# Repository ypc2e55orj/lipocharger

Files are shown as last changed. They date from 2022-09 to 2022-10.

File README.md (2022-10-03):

# Li-Po Charger

小容量リポバッテリー充電器





## 仕様

- 電源入力 (5V)
    - USB Type-C
    - 2.54mm ピンヘッダ
- 充電電圧・電流 (1個あたり)
    - 4.2V / 50mA

USB Type-Cとピンヘッダから同時に入力された場合、ピンヘッダからの入力を優先する

充電中赤色LED点灯、充電完了時に消灯

## 部品リスト

|概説|メーカー|型番|個数|
|:-:|:-:|:-:|:-:|
|USB Type-Cコネクタ|Korean Hroparts Elec|TYPE-C-31-M-12|1|
|ZHコネクタ|JST|B2B-ZR-3.4(LF)(SN)|4|
|2.54mmピッチ ピンヘッダ 2P|||1|
|リセッタブルヒューズ|Bourns|MF-NSMF050-2|1|
|ショットキーバリアダイオード|東芝セミコンダクター|CUHS20S60|2|
|Pch MOS-FET|International Rectifier|IRLML6402|1|
|青色LED|OptoSupply|OSBL1608C1A|1|
|黄色LED|OptoSupply|OSYL1608C1A|1|
|赤色LED|OptoSupply|OSHR1608C1A|4|
|積層セラミックコンデンサ|muRata|GRM188R71E105KA12|4|
|薄膜抵抗器 5.1kΩ|Panasonic|ERA-3AED512V|2|
|薄膜抵抗器 430Ω|Panasonic|ERA-3AED431V|1|
|薄膜抵抗器 1kΩ|Panasonic|ERA-3AED102V|1|
|薄膜抵抗器 680Ω|Panasonic|ERA-3AED681V|5|
|薄膜抵抗器 20kΩ|Panasonic|ERA-3AED203V|4|
|Li-Ion充電管理IC|Analog Devices|LTC4054XES5-4.2|4|

## LICENSE

The MIT License

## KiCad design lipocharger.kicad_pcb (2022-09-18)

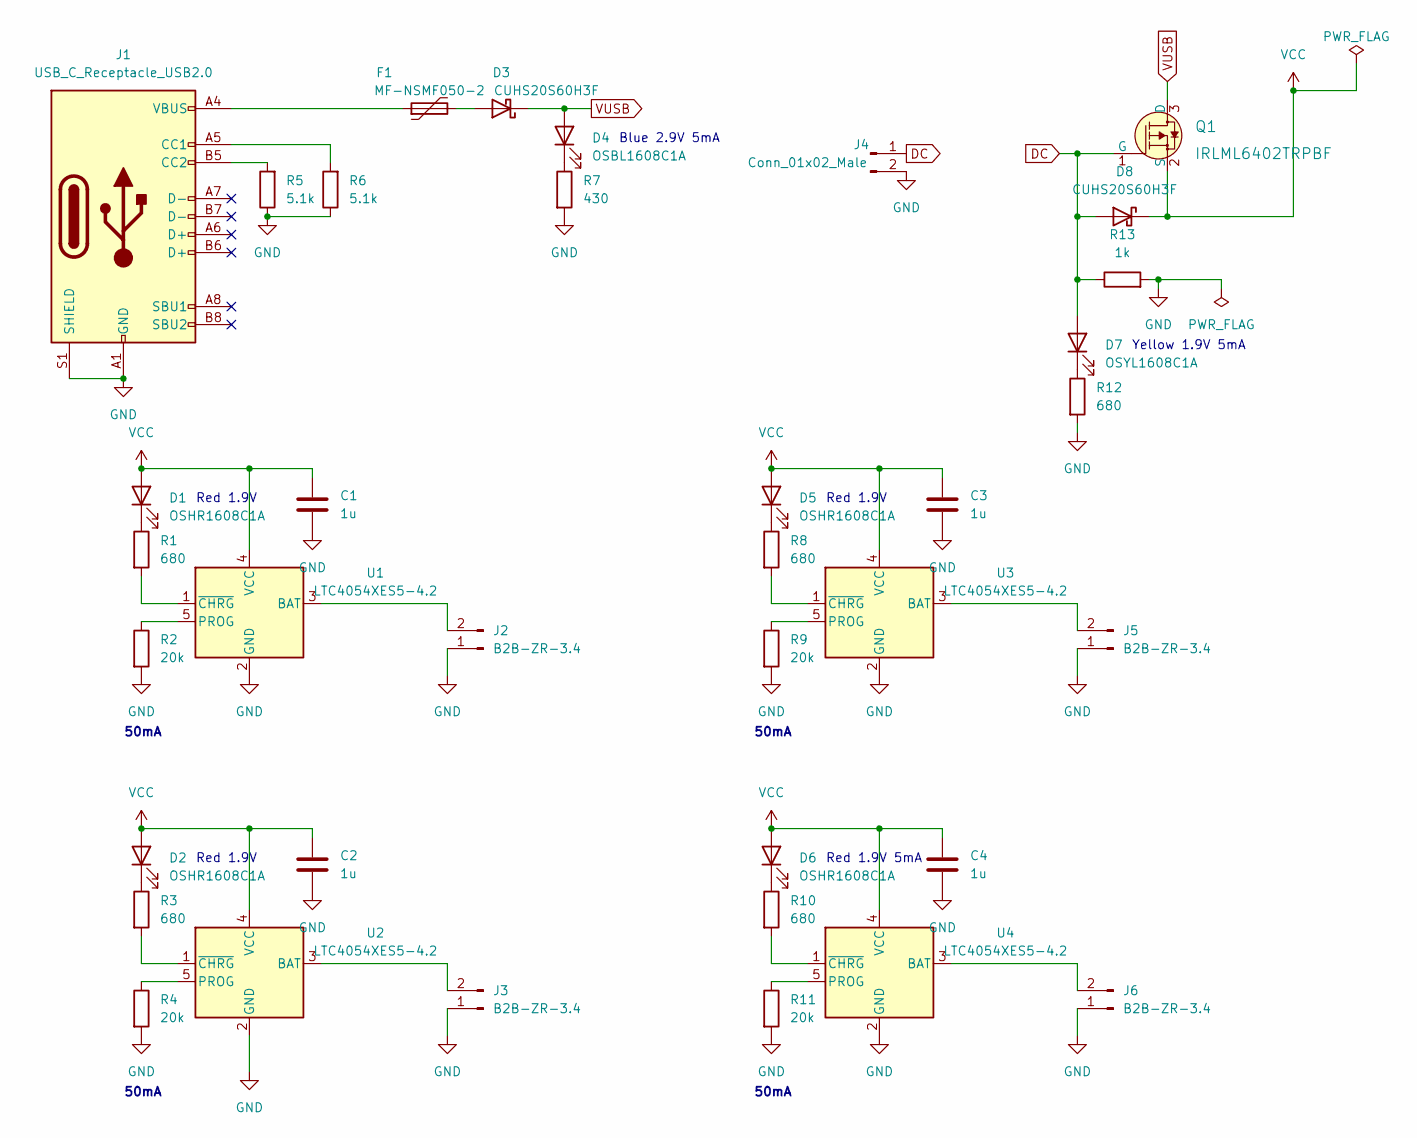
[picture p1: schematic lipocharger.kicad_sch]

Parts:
C1, C2, C3, C4: 1u; C_0603_1608Metric
D1, D2, D5, D6: OSHR1608C1A; C_0603_1608Metric
D3, D8: CUHS20S60H3F; US2H
D4: OSBL1608C1A; C_0603_1608Metric
D7: OSYL1608C1A; C_0603_1608Metric
F1: MF-NSMF050-2; Fuse_1206_3216Metric
J1: USB_C_Receptacle_USB2.0; USB_C_Receptacle_HRO_TYPE-C-31-M-12
J2, J3, J5, J6: B2B-ZR-3.4; JST_ZH-1x2
J4: Conn_01x02_Male; PinHeader_1x02_P2.54mm_Vertical
Q1: IRLML6402TRPBF; SOT-23-3; MPN IRLML6402TRPBF; Digi-Key_PN IRLML6402PBFCT-ND
R1, R3, R8, R10, R12: 680; R_0603_1608Metric
R2, R4, R9, R11: 20k; R_0603_1608Metric
R5, R6: 5.1k; R_0603_1608Metric
R7: 430; R_0603_1608Metric
R13: 1k; R_0603_1608Metric
U1, U2, U3, U4: LTC4054XES5-4.2; TSOT-23-5

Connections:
DC: D7.2 (A), D8.2 (A), J4.1, Q1.1 (G), R13.1
GND: C1.2, C2.2, C3.2, C4.2, J1.A1 (GND), J1.A12 (GND), J1.B1 (GND), J1.B12 (GND), J1.S1 (SHIELD), J2.1, J3.1, J4.2, J5.1, J6.1, R2.2, R4.2, R5.1, R6.1, R7.2, R9.2, R11.2, R12.2, R13.2, U1.2 (GND), U2.2 (GND), U3.2 (GND), U4.2 (GND)
unnamed: D1.1 (K), R1.1
unnamed: D2.1 (K), R3.1
unnamed: D3.2 (A), F1.2
unnamed: D4.1 (K), R7.1
unnamed: D5.1 (K), R8.1
unnamed: D6.1 (K), R10.1
unnamed: D7.1 (K), R12.1
unnamed: F1.1, J1.A4 (VBUS), J1.A9 (VBUS), J1.B4 (VBUS), J1.B9 (VBUS)
unnamed: J1.A5 (CC1), R6.2
unnamed: J1.B5 (CC2), R5.2
unnamed: J2.2, U1.3 (BAT)
unnamed: J3.2, U2.3 (BAT)
unnamed: J5.2, U3.3 (BAT)
unnamed: J6.2, U4.3 (BAT)
unnamed: R1.2, U1.1 (~CHRG)
unnamed: R2.1, U1.5 (PROG)
unnamed: R3.2, U2.1 (~CHRG)
unnamed: R4.1, U2.5 (PROG)
unnamed: R8.2, U3.1 (~CHRG)
unnamed: R9.1, U3.5 (PROG)
unnamed: R10.2, U4.1 (~CHRG)
unnamed: R11.1, U4.5 (PROG)
VCC: C1.1, C2.1, C3.1, C4.1, D1.2 (A), D2.2 (A), D5.2 (A), D6.2 (A), D8.1 (K), Q1.2 (S), U1.4 (VCC), U2.4 (VCC), U3.4 (VCC), U4.4 (VCC)
VUSB: D3.1 (K), D4.2 (A), Q1.3 (D)

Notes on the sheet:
50mA
Red 1.9V
Yellow 1.9V 5mA
Red 1.9V 5mA
Blue 2.9V 5mA

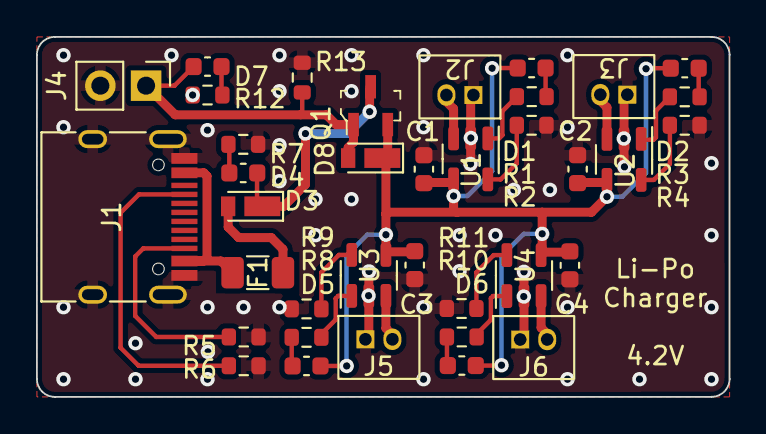
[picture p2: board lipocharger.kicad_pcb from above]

Board: 2 copper layers, 38.5 x 20.0 mm, 37 parts (0 on the bottom side), 26 nets.

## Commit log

2022-09-18 Add voltage specification
2022-09-18 Add sample image
2022-10-03 Add circuit image
